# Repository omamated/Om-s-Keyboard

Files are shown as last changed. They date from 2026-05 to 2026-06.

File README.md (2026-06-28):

# My Keyboard

- A custom low-profile wireless mechanical keyboard designed from scratch to match the coolness of the Apple Magic Keyboard while teaching me PCB design, firmware development, and CAD. I know it looks pretty simple, but it took me a long time to make it and I'm pretty proud of it



## Overview

This keyboard is a mechanical and wireless built with the Nice!Nano V2 microcontroller and will use ZMK firmware. My idea was to create a minimal keyboard that matches my dad's MacBook Pro which I occasionally use.

Instead of buying an existing keyboard, I decided to design it myself, so I could learn software like Kicad and Fusion360 more.

The keyboard features:

* Bluetooth connectivity using ZMK firmware
* Nice!Nano V2 controller
* Hot-swappable switches
* Custom Pikachu-themed 3D-printed enclosure
* Rechargeable battery 10000 mah
* Low-profile design

# Why I Built This

I've been using a basic keyboard for a long time and wanted something that felt more premium and minimalist. I wanted something that wasn't that bulky, but still stood out, so I designed the pikachu minamalist keyboard. This keyboard helped me learn major software for the laptop I'm building in the future.

# The Process

## PCB Design

The PCB was designed in KiCad.

Since I was still kinda new to KiCad, I spent a lot of time learning footprint selection, routing techniques, and manufacturing requirements. The PCB includes a way for me to charge a battery using the Nice!Nano. The PCB also uses a matrix to make all the switches fit. 

### Final PCB image

 

## Schematic Design

The schematic wasn't that bad for me to do as I learned a decent amount from my macropad, so I didn't spend most of my time here. Most of my time was spent on finding the right symbols. I later learned that the symbol doesn't matter at all if you have the right footprint.

### Final Schematic images





## Case Design

The enclosure was designed in Fusion 360. My initial design was very basic, practically just a box with screws.

### Version 2

After reviewing the first version, I increased the case thickness and improved the mounting system. I added thicker walls as the thin walls would lead to snapping.

### Version 3 
Made the case a whole pikachu theme, I will print this in yellow to make it something unique to me. I also added a honey comb pattern at the bottom. To me, this was by far the best version and the one I'm the most proud of.







# Manufacturing Plan

The keyboard will be assembled using the following process. You will first need to order the PCB and all of the otherb parts in the BOM. Once you recieve all the parts and the PCB, you can start soldering them all and then you can flash ZMK software onto the Nice!Nano. Once thats working you can assemble the case, which means you need to put the heat inserts and screw it together.

# Problems

This project made me learn plenty of things that I didn't know very well before.

### Learning KiCad

Although I had some previous experience creating a macropad, this wass my first PCB project without a tutorial

### Routing the PCB

I had to route the PCB about 5 times as it was very confusing to do.

# What I Learned

Through this project I learned how to use PCB design softwares better, how to use ZMK, and how to use fusion 360 efficiently.

# Resources

The following resources were especially helpful during development:

### PCB Design

https://www.youtube.com/watch?v=7UXsD7nSfDY

### Keyboard Design

ScottO'KeeBs YouTube Channel

### Software
 I used Kicad, Fusion360, and ZMK

---

# Bill of Materials
(links are in BOM.csv)

| Item | Cost | Quantity |
| --- | --- | --- |
| Low Profile Switches | $15 | 80 |
| Nice!Nano V2 | $25 | 1 |
| Diodes | $6 | 80 (only packs of ten) |
| Custom Keyboard PCB | $30 | 1 (Minimum order is 5) |
| Hot-swap Sockets | $12 | 80 |
| Power Switch | $1.50 | 1 (minimum order is 2) |
| Battery Jack | $1 | 1 (minimum order is 2) |
| Battery | $7 | 1 |
| Filament for Case | $20 | 1 |
| Heat Inserts & Screws | $8 | 1 (M2.5 should work) |

Estimated Total: $136 (before tax + Shipping)

---

# Future Improvements

Potential future upgrades include:

* CNC (I think) enclosure
* Magnetic charging system (maybe for me to use in a custom laptop I'm designing?)
* Lower-profile enclosure revisions
* Improved battery mounting
* Custom keycaps

# Gallery/Images

### PCB Render



Although it is quite tight the hot-swap pocket does fit under the Nice nano, which I anticipated as per my resources.


### Schematic





### Updated Case







### Zine Page

Ok look, my Zine was saved in canva (under my school account), so it was hard for me to add the new case on the back side, so I hope y'all will let it slide.

Zine_keyboard_new

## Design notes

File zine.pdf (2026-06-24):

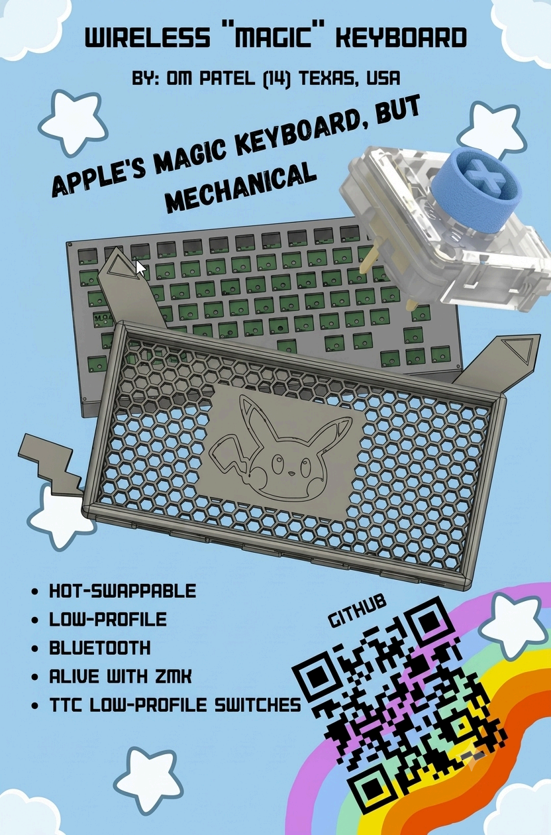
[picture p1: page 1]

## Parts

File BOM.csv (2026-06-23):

Item | Cost | Link | Store | Quantity
Low Profile Switches | $15 | https://mechanicalkeyboards.com/products/ttc-low-profile-blue-40g-clicky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 | Mechanical Keyboards | 80(only packs of ten)
Nice!NanoV2 | $25 | https://typeractive.xyz/products/nice-nano | Typeractive | 1
Diodes | $6 | https://typeractive.xyz/products/smd-diodes | Typeractive | 80(only packs of ten)
Custom Keyboard PCB | $30 | Jlcpcb.com | JLCPCB | 1 (Minimum order is 5 though)
Hotswap pockets | $12 | https://typeractive.xyz/products/hotswap-sockets?variant=45742200324327 | Typeractive | 80
Powerswitch | $1.50 | https://typeractive.xyz/products/power-switch | Typeractive | 1 (minimum order is 2)
Battery Jack | $1 | https://typeractive.xyz/products/battery-jack?variant=46024892186855 | Typeractive | 1 (minimum order is 2)
Battery | $7 | ,https://www.aliexpress.us/item/3256809148927180.html?src=google&gatewayAdapt=glo2usa | Aliexpress | 1
Filament for Case | $20(filament) | https://www.amazon.com/ELEGOO-Filament-Dimensional-Accuracy-Cardboard/dp/B0BM72Z1X5 | Amazon | 1
Heat inserts & screws (M2.5 should work) | $8 | https://www.aliexpress.us/item/3256804651118796.html?curPageLogUid=gXG5LX093uy3 | Aliexpress | Need 4 (set of 500)
Total | $136

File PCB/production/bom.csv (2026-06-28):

Designator | Footprint | Quantity | Value | LCSC Part #
D1, D10, D11, D12, D13, D14, D15, D16, D17, D18, D19, D2, D20, D21, D22, D23, D24, D25, D26, D27, D28, D29, D3, D30, D31, D32, D33, D34, D35, D36, D37, D38, D39, D4, D40, D41, D42, D43, D44, D45, D46, D47, D48, D49, D5, D50, D51, D52, D53, D54, D55, D56, D57, D58, D59, D6, D60, D61, D62, D63, D64, D65, D66, D67, D68, D69, D7, D70, D71, D72, D73, D74, D75, D76, D77, D78, D79, D8, D9 | Diode_SOD-123 | 79 | ~
J1 | JST_PH_S2B-PH-K_1x02_P2.00mm_Horizontal | 1 | Conn_01x02_Socket
S1, S10, S11, S12, S13, S14, S15, S16, S17, S18, S19, S2, S20, S21, S22, S23, S24, S25, S26, S27, S28, S29, S3, S30, S31, S32, S33, S34, S35, S36, S37, S38, S39, S4, S40, S41, S42, S43, S44, S45, S46, S47, S48, S49, S5, S50, S51, S52, S53, S54, S55, S56, S57, S58, S59, S6, S60, S61, S62, S63, S64, S65, S66, S67, S68, S69, S7, S70, S71, S72, S73, S74, S75, S76, S77, S78, S79, S8, S9 | Hotswap_MX_1.00u | 79 | ~
SW1 | SW_SPDT_PCM12 | 1 | SW_SPDT_312
U1 | Nice_Nano_V2 | 1 | Nice_Nano_V2

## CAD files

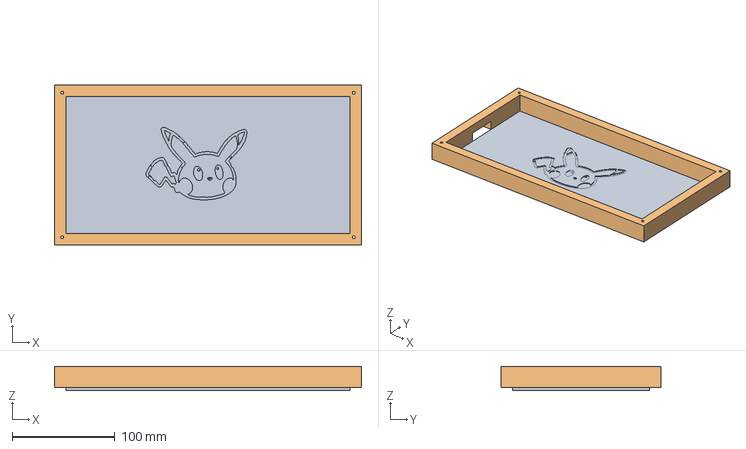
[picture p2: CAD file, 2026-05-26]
CAD/Case/case_better.step
298.2 x 155.3 x 23.6 mm

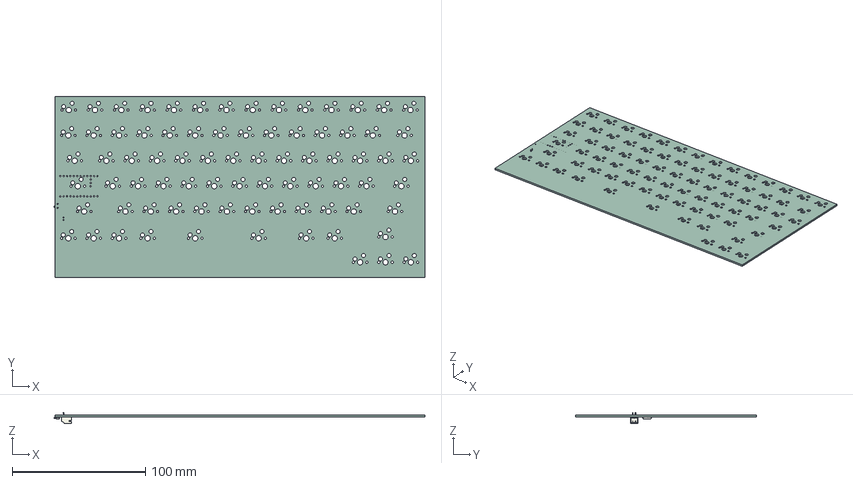
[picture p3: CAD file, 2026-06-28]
CAD/Full Assembly/pcb.step
278.5 x 136.2 x 8.25 mm
JST_PH_S2B-PH-K_1x02_P2.00mm_Horizontal
SW_SPDT_PCM12
Keyboard_lowprofile_PCB

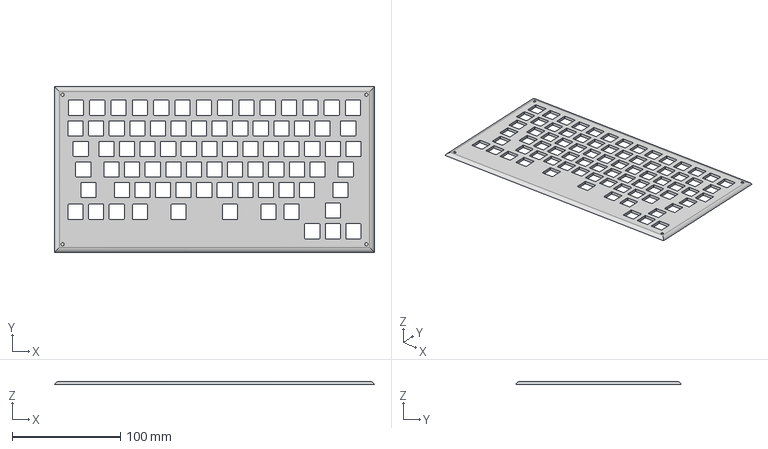
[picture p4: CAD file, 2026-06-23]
CAD/Top-Plate-Case/plate_better.step
296.2 x 153.3 x 3.00 mm

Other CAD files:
CAD/Case/case_better.f3d
CAD/Case/case_better.stl
CAD/Top-Plate-Case/plate_better.f3d
CAD/Top-Plate-Case/plate_better.stl

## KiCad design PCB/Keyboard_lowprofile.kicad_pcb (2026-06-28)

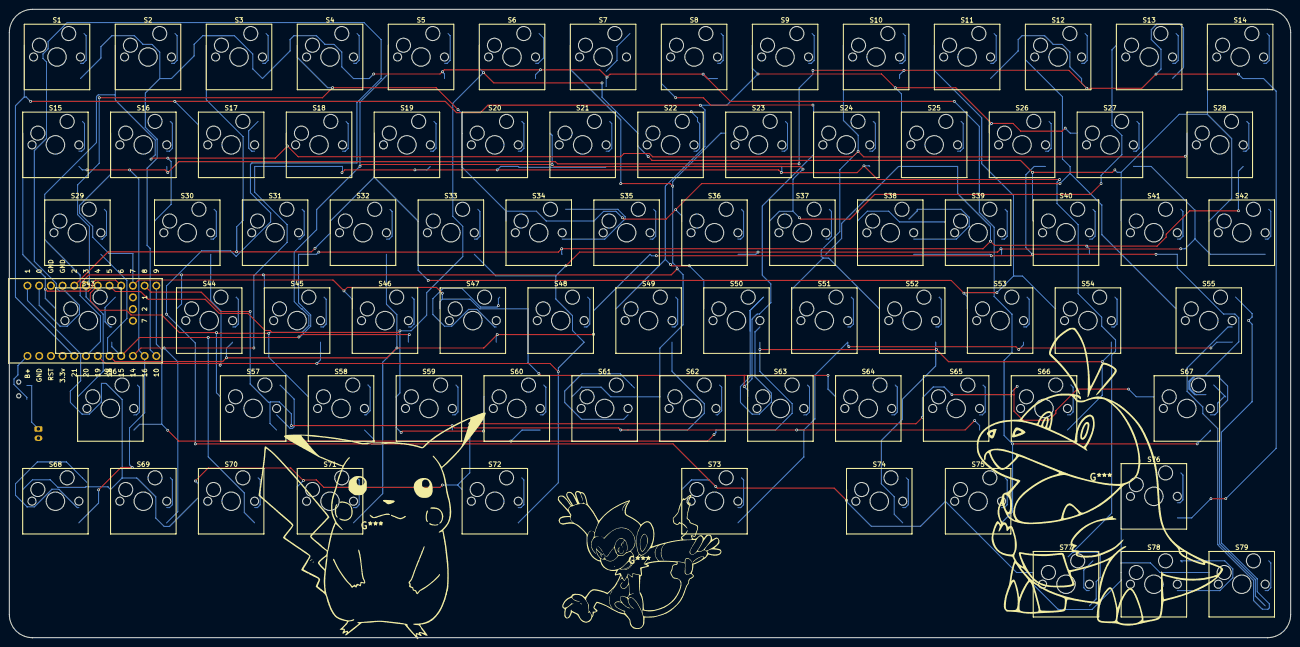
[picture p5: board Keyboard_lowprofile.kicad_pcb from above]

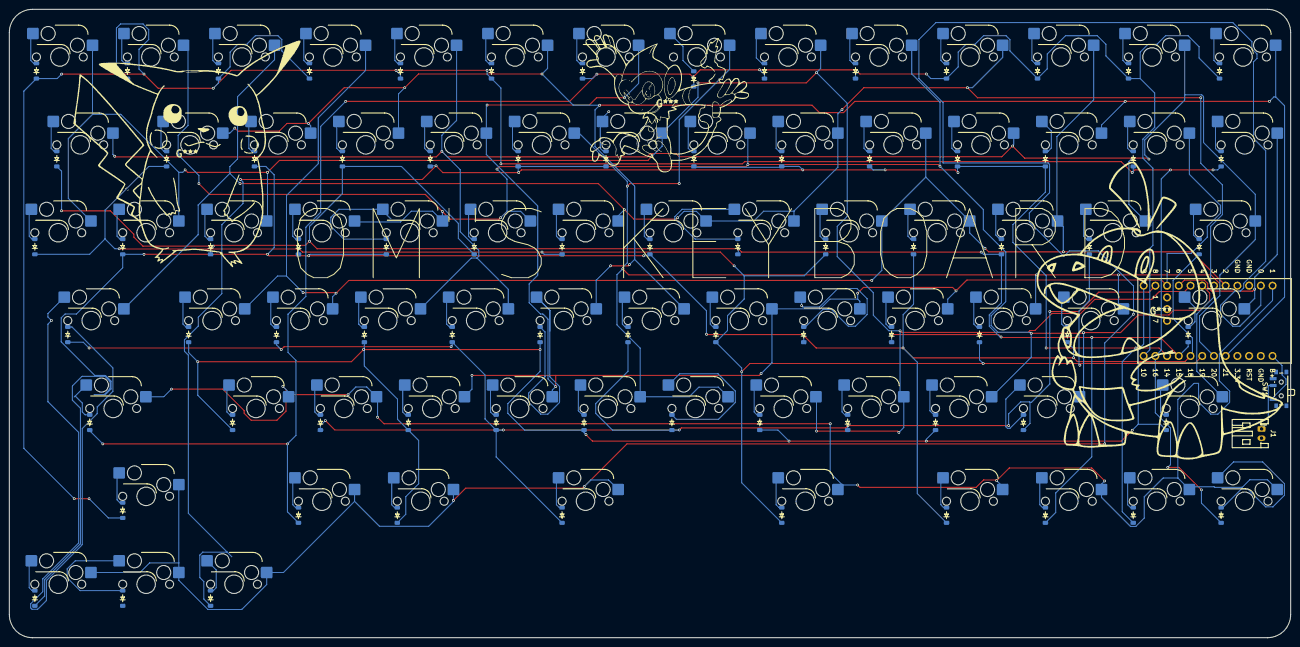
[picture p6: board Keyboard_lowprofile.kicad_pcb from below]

Board: 2 copper layers, 277.8 x 136.2 mm, 161 parts (82 on the bottom side), 99 nets.

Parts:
D1, D2, D3, D4, D5, D6, D7, D8, D9, D10, D11, D12, D13, D14, D15, D16, D17, D18, D19, D20, D21, D22, D23, D24, D25, D26, D27, D28, D29, D30, D31, D32, D33, D34, D35, D36, D37, D38, D39, D40, D41, D42, D43, D44, D45, D46, D47, D48, D49, D50, D51, D52, D53, D54, D55, D56, D57, D58, D59, D60, D61, D62, D63, D64, D65, D66, D67, D68, D69, D70, D71, D72, D73, D74, D75, D76, D77, D78, D79: Diode_SOD-123
J1: Conn_01x02_Socket; JST_PH_S2B-PH-K_1x02_P2.00mm_Horizontal
S1, S2, S3, S4, S5, S6, S7, S8, S9, S10, S11, S12, S13, S14, S15, S16, S17, S18, S19, S20, S21, S22, S23, S24, S25, S26, S27, S28, S29, S30, S31, S32, S33, S34, S35, S36, S37, S38, S39, S40, S41, S42, S43, S44, S45, S46, S47, S48, S49, S50, S51, S52, S53, S54, S55, S56, S57, S58, S59, S60, S61, S62, S63, S64, S65, S66, S67, S68, S69, S70, S71, S72, S73, S74, S75, S76, S77, S78, S79: Hotswap_MX_1.00u
SW1: SW_SPDT_312; SW_SPDT_PCM12
U1: Nice_Nano_V2

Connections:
Column 0: S1.1, S9.1, S17.1, S25.1, S26.1, S27.1, S49.1, S50.1, U1.20 (21)
Column 1: S2.1, S10.1, S18.1, S28.1, S29.1, S30.1, S51.1, S52.1, U1.19 (20)
Column 2: S3.1, S11.1, S19.1, S31.1, S32.1, S33.1, S53.1, S54.1, U1.5 (2)
Column 3: S4.1, S12.1, S20.1, S34.1, S35.1, S36.1, S55.1, S56.1, U1.6 (3)
Column 4: S5.1, S13.1, S21.1, S37.1, S38.1, S39.1, S57.1, S58.1, U1.7 (4)
Column 5: S6.1, S14.1, S22.1, S40.1, S41.1, S42.1, S59.1, S60.1, U1.8 (5)
Column 6: S7.1, S15.1, S23.1, S43.1, S44.1, S45.1, S61.1, S62.1, U1.9 (6)
Column 7: S8.1, S16.1, S24.1, S46.1, S47.1, S48.1, S63.1, S64.1, U1.10 (7)
Column 8: S65.1, S66.1, S67.1, S68.1, S69.1, S70.1, S71.1, S72.1, U1.1
Column 9: S73.1, S74.1, S75.1, S76.1, S77.1, S78.1, S79.1, U1.2 (0)
unnamed: D1.2 (A), S1.2
unnamed: D2.2 (A), S2.2
unnamed: D3.2 (A), S3.2
unnamed: D4.2 (A), S4.2
unnamed: D5.2 (A), S5.2
unnamed: D6.2 (A), S6.2
unnamed: D7.2 (A), S7.2
unnamed: D8.2 (A), S8.2
unnamed: D9.2 (A), S9.2
unnamed: D10.2 (A), S10.2
unnamed: D11.2 (A), S11.2
unnamed: D12.2 (A), S12.2
unnamed: D13.2 (A), S13.2
unnamed: D14.2 (A), S14.2
unnamed: D15.2 (A), S15.2
unnamed: D16.2 (A), S16.2
unnamed: D17.2 (A), S17.2
unnamed: D18.2 (A), S18.2
unnamed: D19.2 (A), S19.2
unnamed: D20.2 (A), S20.2
unnamed: D21.2 (A), S21.2
unnamed: D22.2 (A), S22.2
unnamed: D23.2 (A), S23.2
unnamed: D24.2 (A), S24.2
unnamed: D25.2 (A), S25.2
unnamed: D26.2 (A), S26.2
unnamed: D27.2 (A), S27.2
unnamed: D28.2 (A), S28.2
unnamed: D29.2 (A), S29.2
unnamed: D30.2 (A), S30.2
unnamed: D31.2 (A), S31.2
unnamed: D32.2 (A), S32.2
unnamed: D33.2 (A), S33.2
unnamed: D34.2 (A), S34.2
unnamed: D35.2 (A), S35.2
unnamed: D36.2 (A), S36.2
unnamed: D37.2 (A), S37.2
unnamed: D38.2 (A), S38.2
unnamed: D39.2 (A), S39.2
unnamed: D40.2 (A), S40.2
unnamed: D41.2 (A), S41.2
unnamed: D42.2 (A), S42.2
unnamed: D43.2 (A), S43.2
unnamed: D44.2 (A), S44.2
unnamed: D45.2 (A), S45.2
unnamed: D46.2 (A), S46.2
unnamed: D47.2 (A), S47.2
unnamed: D48.2 (A), S48.2
unnamed: D49.2 (A), S49.2
unnamed: D50.2 (A), S50.2
unnamed: D51.2 (A), S51.2
unnamed: D52.2 (A), S52.2
unnamed: D53.2 (A), S53.2
unnamed: D54.2 (A), S54.2
unnamed: D55.2 (A), S55.2
unnamed: D56.2 (A), S56.2
unnamed: D57.2 (A), S57.2
unnamed: D58.2 (A), S58.2
unnamed: D59.2 (A), S59.2
unnamed: D60.2 (A), S60.2
unnamed: D61.2 (A), S61.2
unnamed: D62.2 (A), S62.2
unnamed: D63.2 (A), S63.2
unnamed: D64.2 (A), S64.2
unnamed: D65.2 (A), S65.2
unnamed: D66.2 (A), S66.2
unnamed: D67.2 (A), S67.2
unnamed: D68.2 (A), S68.2
unnamed: D69.2 (A), S69.2
unnamed: D70.2 (A), S70.2
unnamed: D71.2 (A), S71.2
unnamed: D72.2 (A), S72.2
unnamed: D73.2 (A), S73.2
unnamed: D74.2 (A), S74.2
unnamed: D75.2 (A), S75.2
unnamed: D76.2 (A), S76.2
unnamed: D77.2 (A), S77.2
unnamed: D78.2 (A), S78.2
unnamed: D79.2 (A), S79.2
unnamed: J1.1, SW1.2 (C)
unnamed: SW1.1 (B), U1.24 (B+)
Row 0: D49.1 (K), D51.1 (K), D53.1 (K), D55.1 (K), D57.1 (K), D59.1 (K), D61.1 (K), D63.1 (K), D65.1 (K), D73.1 (K), U1.11 (8)
Row 1: D50.1 (K), D52.1 (K), D54.1 (K), D56.1 (K), D58.1 (K), D60.1 (K), D62.1 (K), D64.1 (K), D66.1 (K), D74.1 (K), U1.12 (9)
Row 2: D1.1 (K), D2.1 (K), D3.1 (K), D4.1 (K), D5.1 (K), D6.1 (K), D7.1 (K), D8.1 (K), D67.1 (K), D75.1 (K), U1.13 (10)
Row 3: D9.1 (K), D10.1 (K), D11.1 (K), D12.1 (K), D13.1 (K), D14.1 (K), D15.1 (K), D16.1 (K), D68.1 (K), D76.1 (K), U1.14 (16)
Row 4: D17.1 (K), D18.1 (K), D19.1 (K), D20.1 (K), D21.1 (K), D22.1 (K), D23.1 (K), D24.1 (K), D69.1 (K), D77.1 (K), U1.15 (14)
Row 5: D25.1 (K), D28.1 (K), D31.1 (K), D34.1 (K), D37.1 (K), D40.1 (K), D43.1 (K), D46.1 (K), D70.1 (K), U1.16 (15)
Row 6: D26.1 (K), D29.1 (K), D32.1 (K), D35.1 (K), D38.1 (K), D41.1 (K), D44.1 (K), D47.1 (K), D71.1 (K), D79.1 (K), U1.17 (18)
Row 7: D27.1 (K), D30.1 (K), D33.1 (K), D36.1 (K), D39.1 (K), D42.1 (K), D45.1 (K), D48.1 (K), D72.1 (K), U1.18 (19)

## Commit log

2026-02-01 PCB Files
    [Keyboard_lowprofile.kicad_pcb, Keyboard_lowprofile.kicad_sch]
2026-02-01 Add images for final PCB and schematic
    Added images for final PCB, schematic, and 3D viewer.
2026-02-01 Gerber file
2026-02-01 Add Fusion 360 case image to README
    Added an image of the Fusion 360 case to the README.
2026-02-22 changed cad
    [case_better.step, case_better.stl]
2026-02-22 Revise README with assembly details and formatting
    Updated the README to include planned assembly details and improved formatting.
2026-02-28 Add BOM with item details and costs
2026-03-21 better cad
    ADDED SCREW HOLES
    [case_better.step, case_better.stl, plate_better.step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]
2026-03-27 added source files
    [case_better.f3d, plate_better.f3d]
2026-03-27 added images to readme for screwholes in the case
2026-03-31 Updated CAD Full Assembly
    Wouldn't led me do F3d for a full assembly did F3z instead
2026-04-19 Add link to Wireless Magic Keyboard PDF
2026-04-25 Update battery link to AliExpress
2026-04-25 Update BOM table in README to match BOM.csv data
2026-04-25 Revert battery link back to AliExpress
2026-04-25 Update BOM.csv to use AliExpress battery link
    [BOM.csv]
2026-05-10 Modify BOM.csv to add Quantity columnfew
    Updated BOM.csv to include Quantity column.
    [BOM.csv]
2026-05-10 added new bom(better)
    [BOM.csv]
2026-05-10 Revise Bill of Materials format and total cost
    Updated the Bill of Materials section with new format and corrected total cost.
2026-05-10 Update Bill of Materials to proper markdown table format with all columns
2026-05-22 Update README with new images and case details
    Added new images and updated the case description in README.
2026-05-22 Update BOM.csv to add new items and fix formatting
    [BOM.csv]
2026-05-22 Update BOM in README to match BOM.csv
2026-05-22 Update BOM.csv with new total and item quantities
    Updated BOM.csv to reflect new total cost and item quantities.
    [BOM.csv]
2026-05-22 Fix link and add image in README
    Updated the link for the 'Wireless Magic Keyboard' PDF and added a new image.
2026-05-22 Update BOM.csv to add new items and correct format
    [BOM.csv]
2026-05-22 Modify BOM.csv with new items and updated total
    Updated total cost and added new items to BOM.
    [BOM.csv]
2026-05-22 Add Case to BOM and update total cost
2026-05-26 update CAD
    [case_better.f3d, case_better.step, case_better.stl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]
2026-06-23 Update BOM.csv to include new item links
    [BOM.csv]
2026-06-23 Update BOM.csv with new items and costs
    [BOM.csv]
2026-06-23 Update BOM.csv with new item entries
    [BOM.csv]
2026-06-23 Update BOM with filament entry from BOM.csv
2026-06-23 Add link reference to BOM.csv in README
2026-06-23 Update BOM.csv with revised item details
    Updated BOM with new item costs and links.
    [BOM.csv]
2026-06-23 Updated cad with a better case
    [case_better.f3d, case_better.stl, plate_better.f3d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]
2026-06-23 Update README with version 3 case design and images
    Added new images and updated the case design description for version 3.
2026-06-28 Fixed routes added silkscreen checked if Nice!nano Fits
    [Keyboard_lowprofile.kicad_pcb, Keyboard_lowprofile.kicad_sch, bom.csv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]
